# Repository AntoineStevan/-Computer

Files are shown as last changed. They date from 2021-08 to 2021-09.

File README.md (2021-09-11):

# The mother board of the µ-C1 project.
This repo and project contain all the files used to create the mother board for the µ-C1 computer project.

## Table Of Content.
 - [0  ](https://github.com/AntoineStevan/uComputer-mother-board/tree/main/#0-prerequisites-toc)  Prerequisites.
 - [1  ](https://github.com/AntoineStevan/uComputer-mother-board/tree/main/#1-some-images-toc)    Some images.
 - [2  ](https://github.com/AntoineStevan/uComputer-mother-board/tree/main/#2-open-in-kicad-toc)  Open in KiCAD.
 - [2.1](https://github.com/AntoineStevan/uComputer-mother-board/tree/main/#21-install-kicad-toc) Install KiCAD.
 - [2.2](https://github.com/AntoineStevan/uComputer-mother-board/tree/main/#22-use-kicad-toc)     Use KiCAD.

## 0. Prerequisites. [[toc](https://github.com/AntoineStevan/uComputer-mother-board/tree/main/#table-of-content)]
Some schematics and footprints are custom.  
One can find them [here](https://github.com/AntoineStevan/kicad-libraries).

## 1 Some images. [[toc](https://github.com/AntoineStevan/uComputer-mother-board/tree/main/#table-of-content)]
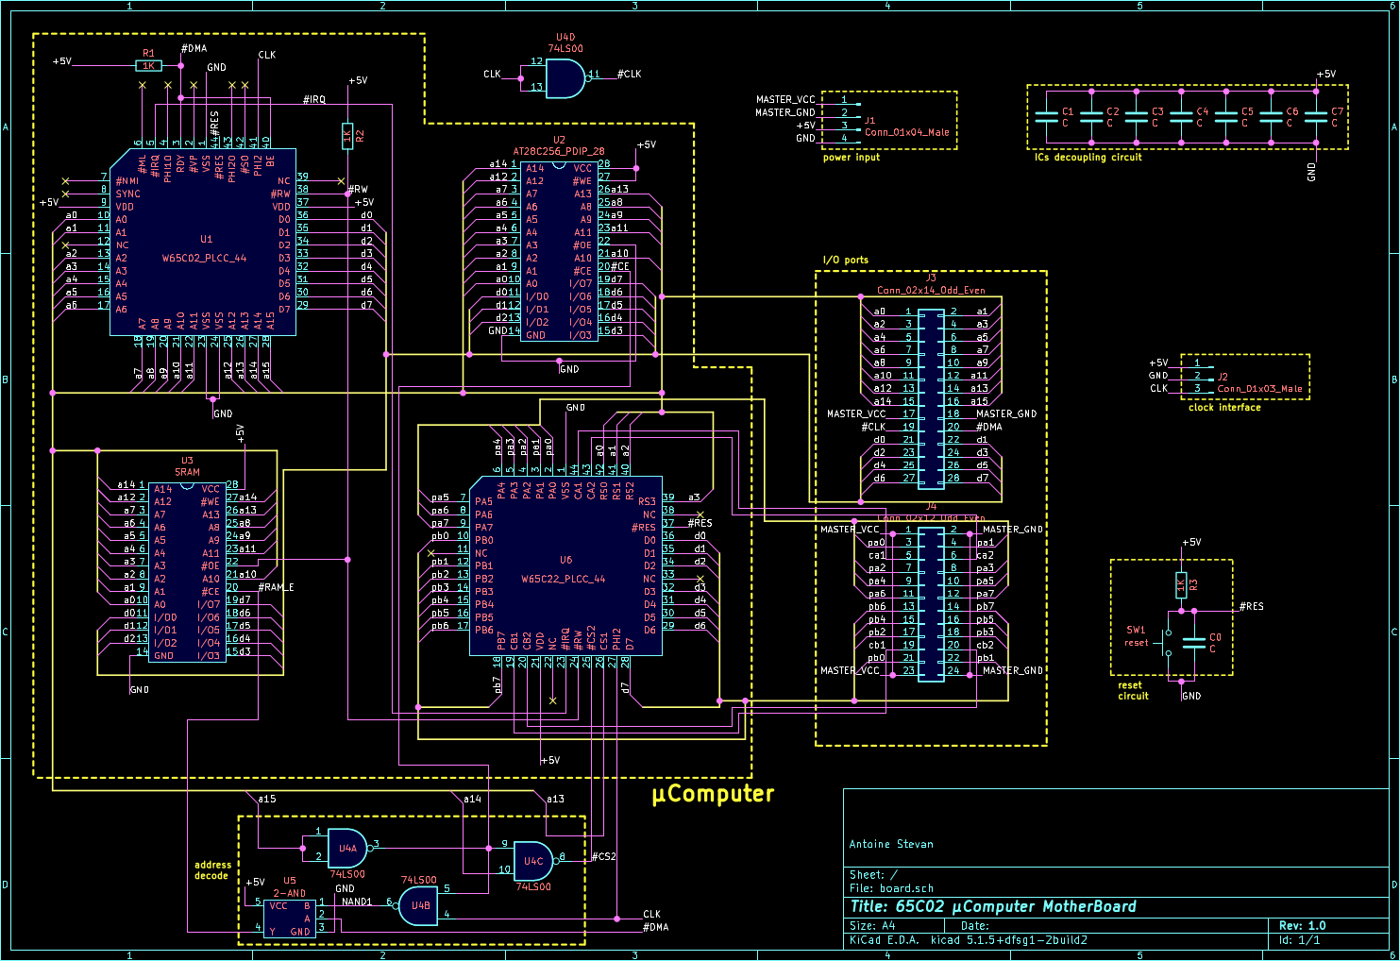
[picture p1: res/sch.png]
||
|:--:|
| *preview of the schematics.* |

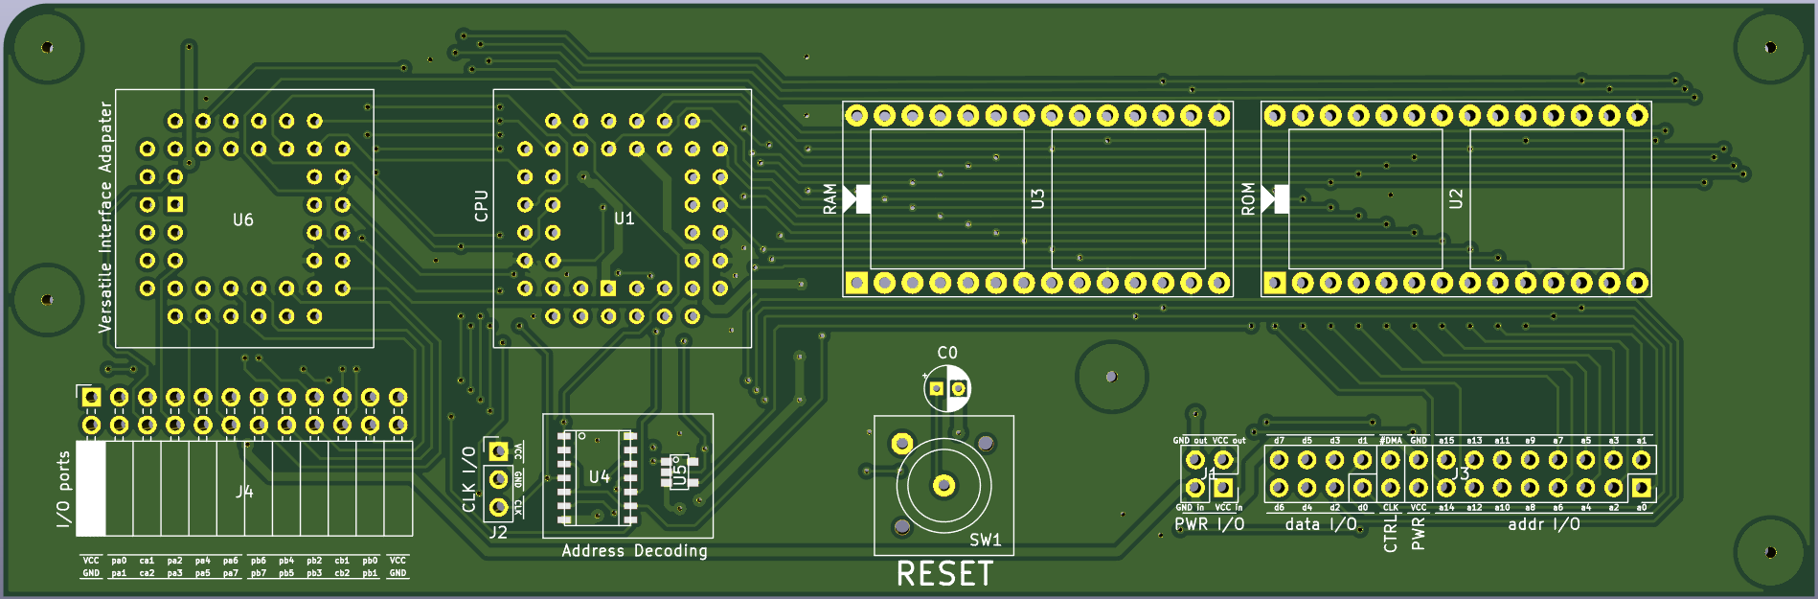
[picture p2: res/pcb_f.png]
||
|:--:|
| *preview of the pcb design (front side).* |

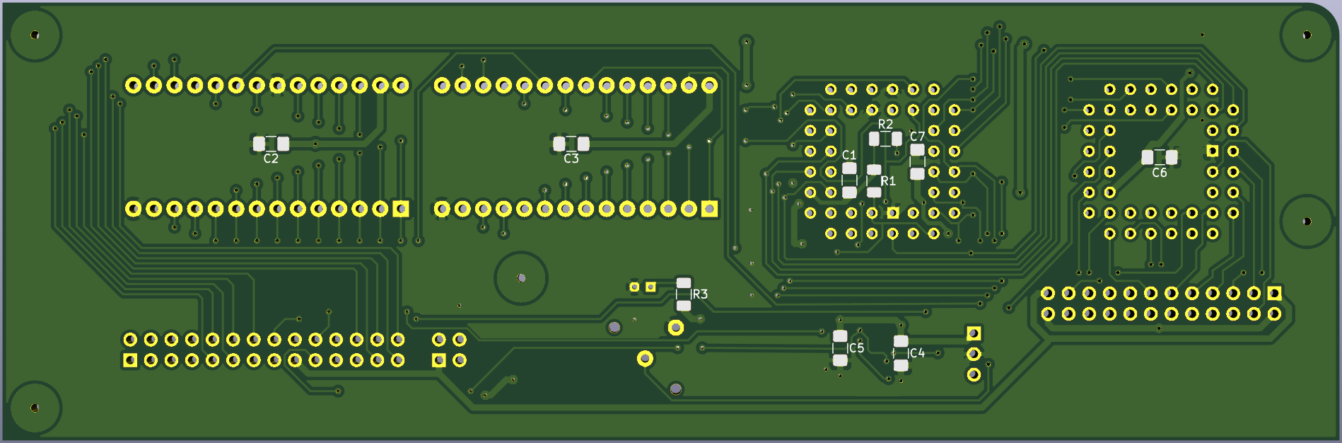
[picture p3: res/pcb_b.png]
||
|:--:|
| *preview of the pcb design (back side).* |

## 2. Open in KiCAD. [[toc](https://github.com/AntoineStevan/uComputer-mother-board/tree/main/#table-of-content)]
This project has been designed under KiCAD, which is, according to their official website, *an open-source software tool for the creation of electronic schematic diagrams and PCB artwork.*  
All usefull official documentation can be found on the website of the Kicad software [here](https://www.kicad.org/).  
Furthermore, parts have been ordered by [Mouser](https://www.mouser.fr/) and PCBs have been manufactured by [JLCPCB](https://jlcpcb.com/).

### 2.1. Install KiCAD. [[toc](https://github.com/AntoineStevan/uComputer-mother-board/tree/main/#table-of-content)]
Official KiCAD material can be found [here](https://docs.kicad.org/5.1/en/getting_started_in_kicad/getting_started_in_kicad.html).  
Further specific material for Linux users can be found [here](https://doc.ubuntu-fr.org/kicad).

### 2.2. Use KiCAD. [[toc](https://github.com/AntoineStevan/uComputer-mother-board/tree/main/#table-of-content)]
The KiCAD team provides plenty of documentation and examples on their official website [here](https://docs.kicad.org/).  
The Internet is also full of great quality tutorials on many topics concerning KiCAD software and schematics/PCB design in general.

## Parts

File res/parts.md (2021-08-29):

| part name | VCC | GND | CAP | qt. | ref. | mouser ref. | ok |
|---|-----|-----|-----|-----|---|---|----|
| 2-NAND gates | 1 | 1 | 1 | 1 |  MC74VHCT132ADR2G | 863-MC74VHCT132ADR2G |  1 |
| 32K SRAM | 1 | 1 | 1 | 1 | CY62256NLL-55SNXI | 913-CY62256NLL55SNXI |  1 |
| 32K eePROM | 1 | 1 | 1 | 1 | AT28C256-15PU | 556-AT28C25615PU |  1 |
| 555 Timer | 1 | 1 | 1 | 1 | LM555CMX/NOPB | 926-LM555CMX/NOPB |  1 |
| 65C02 | 2 | 3 | 2 | 1 | W65C02S6TPLG-14 |  955-W65C02S6TPLG-14 |  1 |
| 65C22 | 1 | 1 | 1 | 1 | W65C22S6TPLG-14 |  955-W65C22S6TPLG-14 |  1 |
| Clock | 1 | 1 | 1 | 1 |  LFSPXO058610Reel | 449-LFSPXO058610REEL |  1 |
| 0.1uF Caps | | | | 8 | | |  1 |
| 0.01uF Caps | | | | 5 | | |  1 |
| 10uF Caps | | | | 1 | | |  1 |
|  1MΩ resistors | | | | 5 | | |  1 |
|  1kΩ resistors | | | | 7 | | |  1 |
| push buttons | | | | 6 | | |  1 |
| switch | | | | 1 | | |  1 |
|  female barrel | | | | 1 | | |  1 |
| green LED | | | | 1 | | | |
| orange LED | | | | 1 | | | |
| red LED | | | | 1 | | | |
| 220Ω resistors | | | | 3 | | |  1 |
| 10kΩ potent. | | | | 1 | | |  1 |
| 1kΩ pull-resi. | | | | 2 | | |  1 |
| | | | | | | | |

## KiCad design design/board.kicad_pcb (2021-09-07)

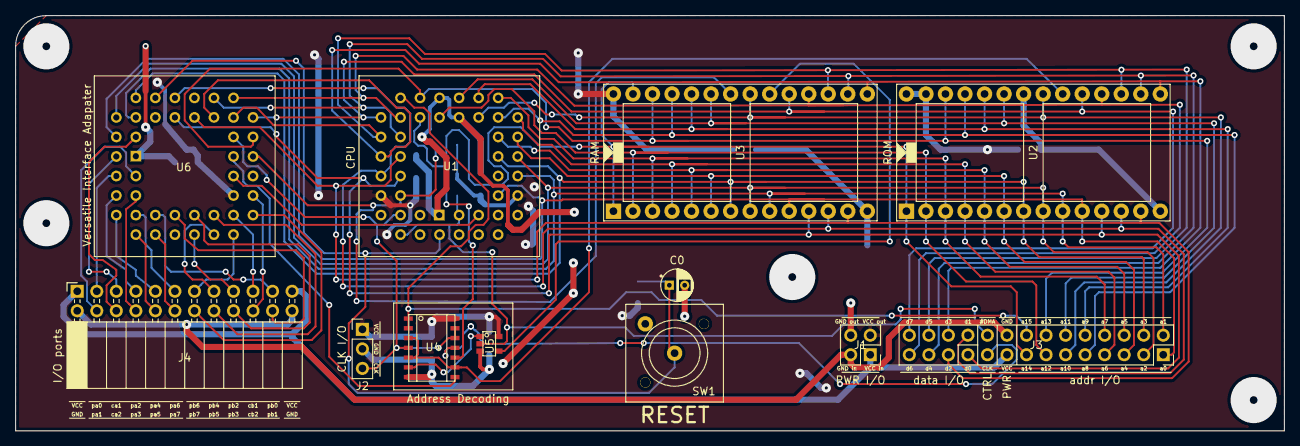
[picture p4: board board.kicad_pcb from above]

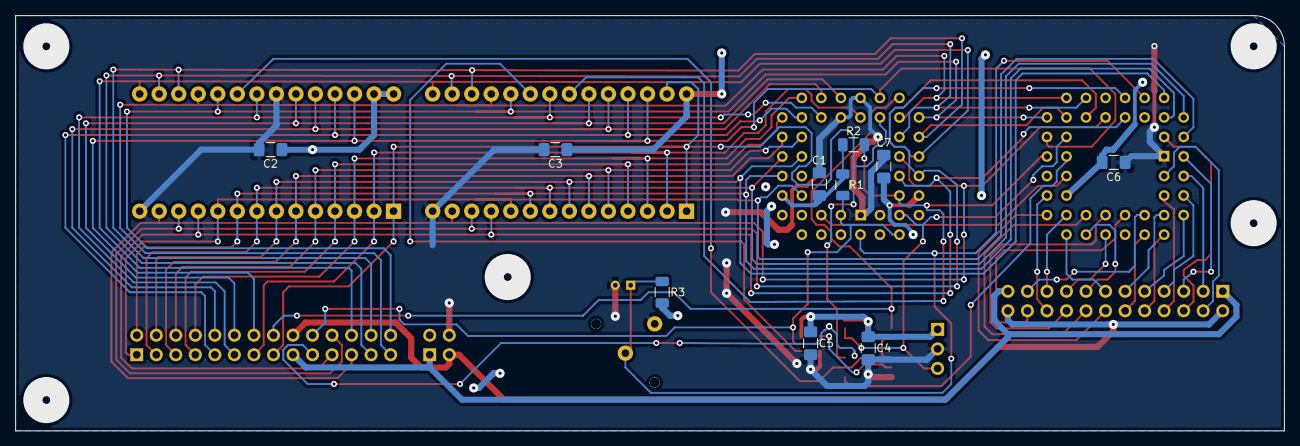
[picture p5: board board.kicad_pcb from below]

Board: 2 copper layers, 165.0 x 54.0 mm, 22 parts (10 on the bottom side), 58 nets.

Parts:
C0: C; CP_Radial_D4.0mm_P2.00mm
C1, C2, C3, C4, C5, C6, C7: C; C_1206_3216Metric_Pad1.42x1.75mm_HandSolder
J1: Conn_01x04_Male; PinHeader_2x02_P2.54mm_Vertical
J2: Conn_01x03_Male; PinHeader_1x03_P2.54mm_Vertical
J3: Conn_02x14_Odd_Even; PinSocket_2x14_P2.54mm_Vertical
J4: Conn_02x12_Odd_Even; PinSocket_2x12_P2.54mm_Horizontal
R1, R2, R3: 1K; R_1206_3216Metric
SW1: reset; pushbutton_switch
U1: W65C02_PLCC_44; SOCKET_PLCC_DIP44_A23.5mm_B23.5mm_C12.7mm_D12.7mm_P2.54mm
U2: AT28C256_PDIP_28; DIP_Socket-28_L35.56_W17.78_H5.1_P2.54
U3: SRAM; DIP_Socket-28_L35.56_W17.78_H5.1_P2.54
U4: 74LS00; SOIC_14_L.1.18_W0.58_P1.27
U5: 2-AND; SC-74A_p0.95
U6: W65C22_PLCC_44; SOCKET_PLCC_DIP44_A23.5mm_B23.5mm_C12.7mm_D12.7mm_P2.54mm

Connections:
/#CE: U2.20, U4.3, U4.5, U4.9
/#CLK: J3.19, U4.11
/#CS2: U4.8, U6.25
/#DMA: J3.20, R1.1, U1.3, U1.40, U5.2
/#IRQ: U1.5, U6.23
/#RAM_E: U3.20, U5.4
/#RES: C0.1, R3.1, SW1.2, U1.44, U6.37
/#RW: R2.1, U1.38, U3.22, U6.24
/+5V: C1.1, C2.1, C3.1, C4.1, C5.1, C6.1, C7.1, J1.3, J2.1, R1.2, R2.2, R3.2, U1.9, U1.37, U2.27, U2.28, U3.28, U5.5, U6.21
/CLK: J2.3, U1.41, U4.4, U4.12, U4.13, U6.27
/GND: C0.2, C1.2, C2.2, C3.2, C4.2, C5.2, C6.2, C7.2, J1.4, J2.2, SW1.1, U1.1, U1.23, U1.24, U2.14, U2.22, U3.14, U5.3, U6.1
/MASTER_GND: J1.2, J3.18, J4.2, J4.24
/MASTER_VCC: J1.1, J3.17, J4.1, J4.23
/NAND1: U4.6, U5.1
/a0: J3.1, U1.10, U2.10, U3.10, U6.42
/a1: J3.2, U1.11, U2.9, U3.9, U6.41
/a2: J3.3, U1.13, U2.8, U3.8, U6.40
/a3: J3.4, U1.14, U2.7, U3.7, U6.39
/a4: J3.5, U1.15, U2.6, U3.6
/a5: J3.6, U1.16, U2.5, U3.5
/a6: J3.7, U1.17, U2.4, U3.4
/a7: J3.8, U1.18, U2.3, U3.3
/a8: J3.9, U1.19, U2.25, U3.25
/a9: J3.10, U1.20, U2.24, U3.24
/a10: J3.11, U1.21, U2.21, U3.21
/a11: J3.12, U1.22, U2.23, U3.23
/a12: J3.13, U1.25, U2.2, U3.2
/a13: J3.14, U1.26, U2.26, U3.26, U6.26
/a14: J3.15, U1.27, U2.1, U3.1, U3.27, U4.10
/a15: J3.16, U1.28, U4.1, U4.2
/ca1: J4.5, U6.44
/ca2: J4.6, U6.43
/cb1: J4.19, U6.19
/cb2: J4.20, U6.20
/d0: J3.21, U1.36, U2.11, U3.11, U6.36
/d1: J3.22, U1.35, U2.12, U3.12, U6.35
/d2: J3.23, U1.34, U2.13, U3.13, U6.34
/d3: J3.24, U1.33, U2.15, U3.15, U6.32
/d4: J3.25, U1.32, U2.16, U3.16, U6.31
/d5: J3.26, U1.31, U2.17, U3.17, U6.30
/d6: J3.27, U1.30, U2.18, U3.18, U6.29
/d7: J3.28, U1.29, U2.19, U3.19, U6.28
/pa0: J4.3, U6.2
/pa1: J4.4, U6.3
/pa2: J4.7, U6.4
/pa3: J4.8, U6.5
/pa4: J4.9, U6.6
/pa5: J4.10, U6.7
/pa6: J4.11, U6.8
/pa7: J4.12, U6.9
/pb0: J4.21, U6.10
/pb1: J4.22, U6.12
/pb2: J4.17, U6.13
/pb3: J4.18, U6.14
/pb4: J4.15, U6.15
/pb5: J4.16, U6.16
/pb6: J4.13, U6.17
/pb7: J4.14, U6.18

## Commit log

2021-08-29 Parts list + first schematics of the mother board.
    [board.sch]
2021-08-30 Replaced old chips with new specific ones + labels.
    [board.sch]
2021-09-03 New I/O ports.
    [board.sch]
2021-09-04 Interface routing.
    [board.sch]
2021-09-04 CPU routing.
    [board.sch]
2021-09-04 Added pcb and net with interface and CPU done.
    [board.kicad_pcb]
2021-09-04 Memory routed.
    [board.kicad_pcb, board.sch]
2021-09-04 Corrected AND gate schematics + start on control.
    [board.kicad_pcb, board.sch]
2021-09-05 Adress + data I/O routed.
    [board.kicad_pcb, board.sch]
2021-09-06 All connections done.
    [board.kicad_pcb]
2021-09-06 File management.
    [board.kicad_pcb, board.sch]
2021-09-06 Silk for I/O ports.
    [board.kicad_pcb]
2021-09-06 gitignore update + new button footprint name.
    [board.kicad_pcb, board.sch]
2021-09-07 Removed svg + pcb views + README update.
2021-09-07 Mounting holes.
    [board.kicad_pcb]
2021-09-07 Negative of schematics + README path correction.
2021-09-07 Better reset switch.
    [board.kicad_pcb]
2021-09-07 Minor changes.
    [board.kicad_pcb, board.sch]
2021-09-11 Link to kicad-libraries + further explainations.
